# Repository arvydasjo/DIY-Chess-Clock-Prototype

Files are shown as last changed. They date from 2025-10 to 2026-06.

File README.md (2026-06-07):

A personal project for a DIY chess clock. This project includes PCB designs, 3D-printable case files, and firmware for a functional chess clock.

<a href="https://example.com">
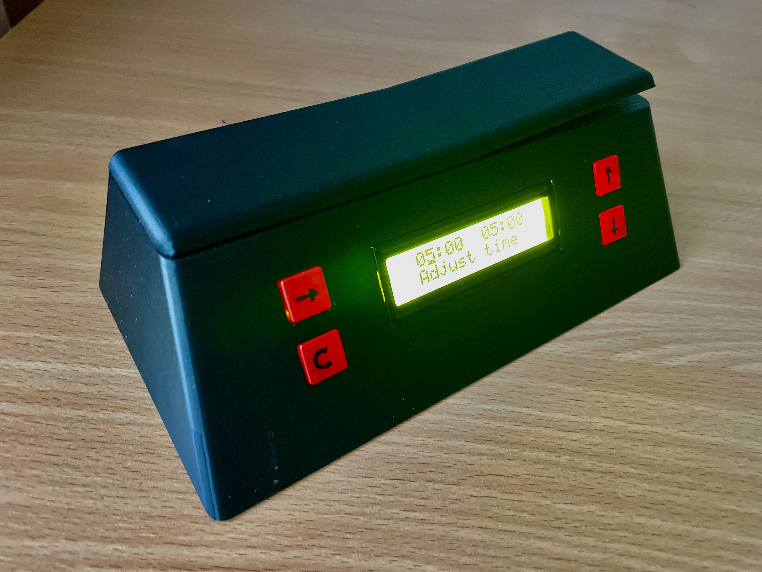
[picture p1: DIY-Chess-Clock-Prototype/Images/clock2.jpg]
  
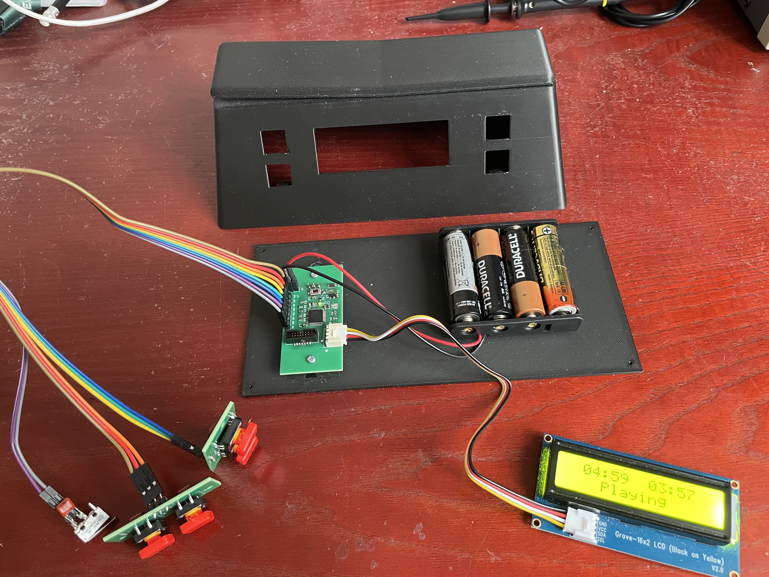
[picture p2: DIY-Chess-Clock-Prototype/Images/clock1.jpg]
  
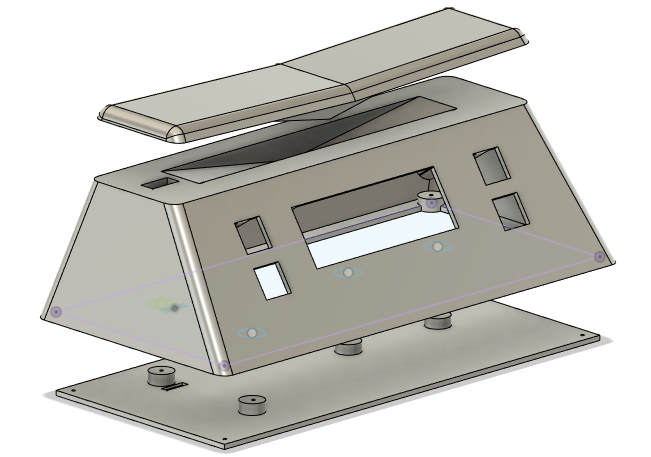
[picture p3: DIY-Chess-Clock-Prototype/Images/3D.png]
  
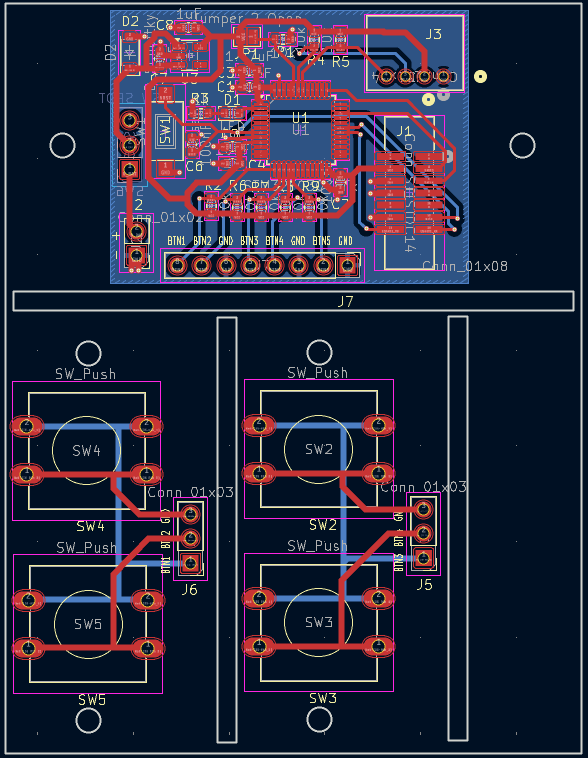
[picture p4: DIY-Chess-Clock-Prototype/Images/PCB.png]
 
</a>

## Features
- Custom PCB with microcontroller STM32F030C8 and screen Grove-LCD 
- 3D-printable case
- small magnets used for the user switch button
- firmware for timing and game management
- Battery-powered

## Files Included
- **PCB/**: Schematic and layout files
- **3D/**: STL files for 3D printing the case
- **Images/**: Prototype pictures
- **Firmware/**: Source code for the microcontroller

## Tools used in the project

- Kicad for PCB design
- STM32CubeIDE + STLINK-V3MINIE for programming, HAL libraries
- Autodesk Fusion for 3D design

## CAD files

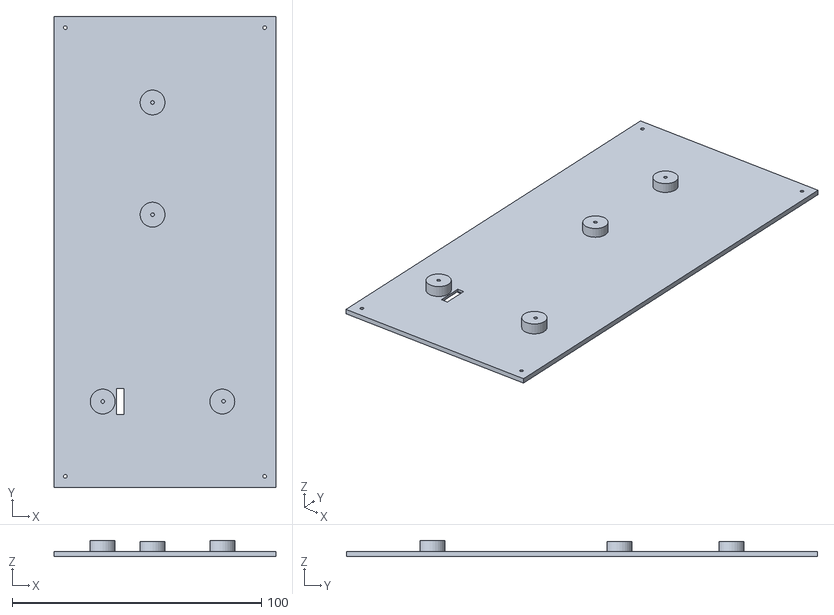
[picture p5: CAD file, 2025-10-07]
DIY-Chess-Clock-Prototype/3D/Box_button.stl
89.0 x 189.0 x 6.50

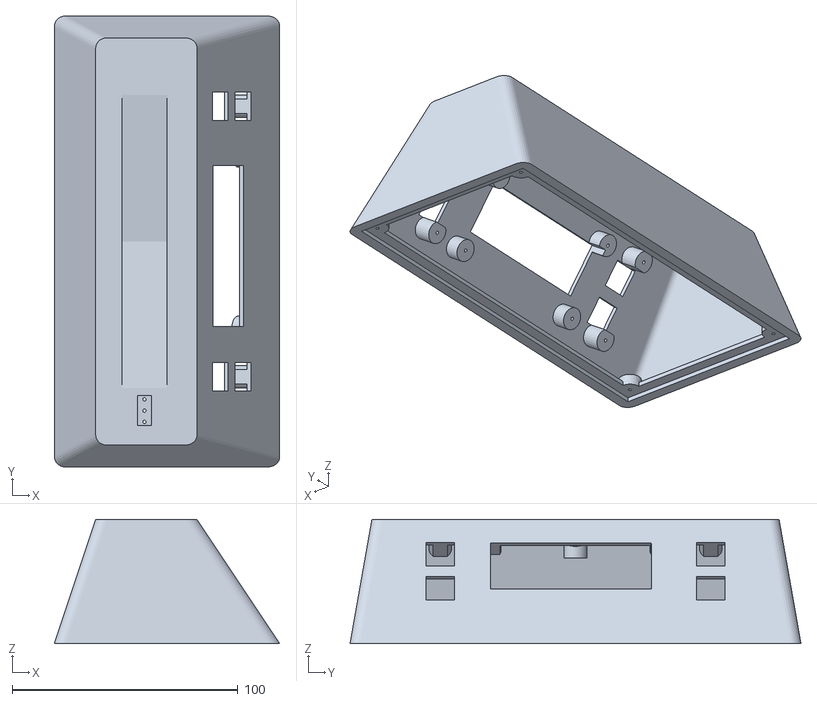
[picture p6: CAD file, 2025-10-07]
DIY-Chess-Clock-Prototype/3D/Box_mid.stl
100.0 x 200.0 x 55.0

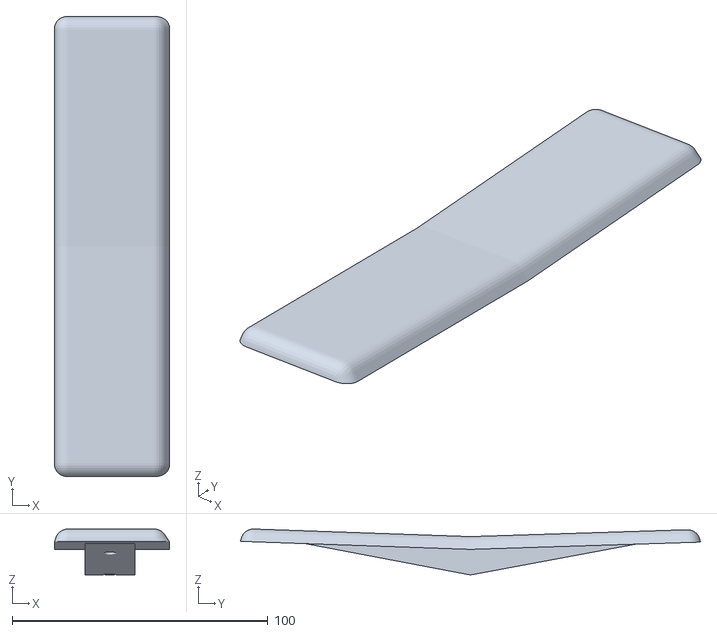
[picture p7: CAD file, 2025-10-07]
DIY-Chess-Clock-Prototype/3D/Box_top.stl
45.0 x 179.8 x 18.0

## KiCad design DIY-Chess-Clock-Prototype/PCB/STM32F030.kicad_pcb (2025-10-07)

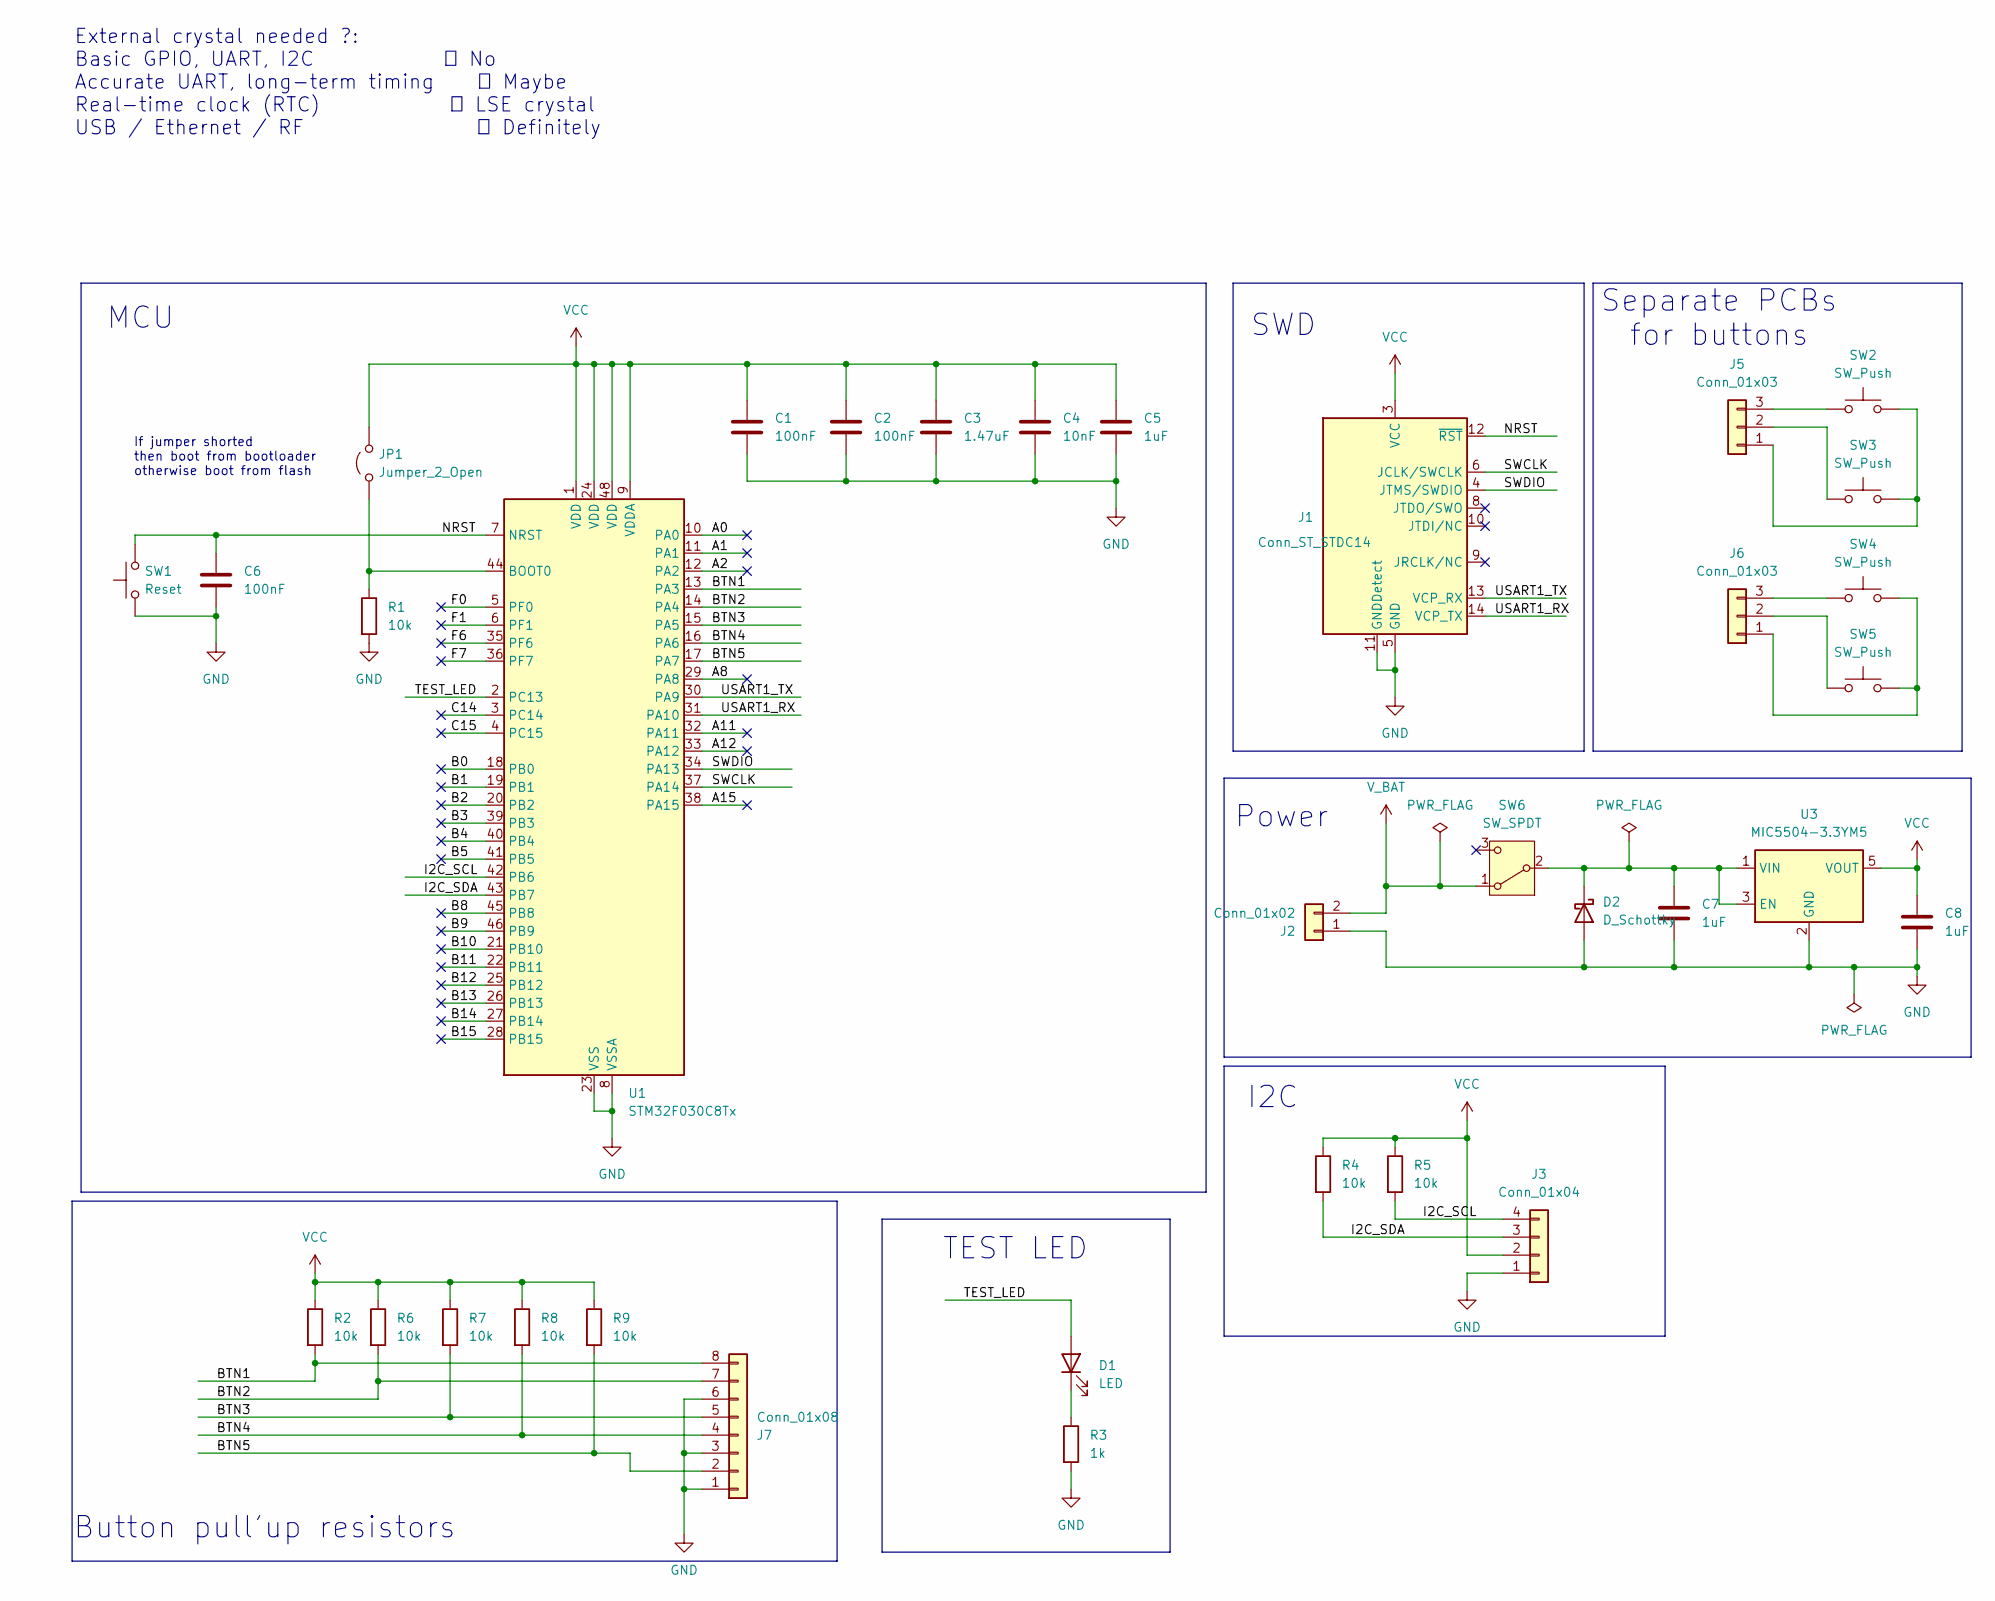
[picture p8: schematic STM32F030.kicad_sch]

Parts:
C1, C2, C6: 100nF; C_0603_1608Metric
C3: 1.47uF; C_0603_1608Metric
C4: 10nF; C_0603_1608Metric
C5, C7, C8: 1uF; C_0603_1608Metric
D1: LED; LED_0603_1608Metric
D2: D_Schottky; D_SOD-123
J1: Conn_ST_STDC14; CONN14_3221-14-0300-00-TR_CNC
J2: Conn_01x02; PinHeader_1x02_P2.54mm_Vertical
J3: Conn_01x04; CONN_S4B-PH-K-S_JST
J5, J6: Conn_01x03; PinHeader_1x03_P2.54mm_Vertical
J7: Conn_01x08; PinHeader_1x08_P2.54mm_Vertical
JP1: Jumper_2_Open; SolderJumper-2_P1.3mm_Open_Pad1.0x1.5mm
R1, R2, R4, R5, R6, R7, R8, R9: 10k; R_0603_1608Metric
R3: 1k; R_0603_1608Metric
SW1: Reset; SW_SPST_CK_RS282G05A3
SW2, SW3, SW4, SW5: SW_Push; SW_PUSH-12mm
SW6: SW_SPDT; PinHeader_1x03_P2.54mm_Vertical
U1: STM32F030C8Tx; LQFP-48_7x7mm_P0.5mm
U3: MIC5504-3.3YM5; SOT-23-5

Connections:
/A0: U1.10 (PA0)
/A1: U1.11 (PA1)
/A2: U1.12 (PA2)
/A8: U1.29 (PA8)
/A11: U1.32 (PA11)
/A12: U1.33 (PA12)
/A15: U1.38 (PA15)
/B0: U1.18 (PB0)
/B1: U1.19 (PB1)
/B2: U1.20 (PB2)
/B3: U1.39 (PB3)
/B4: U1.40 (PB4)
/B5: U1.41 (PB5)
/B8: U1.45 (PB8)
/B9: U1.46 (PB9)
/B10: U1.21 (PB10)
/B11: U1.22 (PB11)
/B12: U1.25 (PB12)
/B13: U1.26 (PB13)
/B14: U1.27 (PB14)
/B15: U1.28 (PB15)
/BTN1: J7.8, R2.2, U1.13 (PA3)
/BTN2: J7.7, R6.2, U1.14 (PA4)
/BTN3: J7.5, R7.2, U1.15 (PA5)
/BTN4: J7.4, R8.2, U1.16 (PA6)
/BTN5: J7.2, R9.2, U1.17 (PA7)
/C14: U1.3 (PC14)
/C15: U1.4 (PC15)
/F0: U1.5 (PF0)
/F1: U1.6 (PF1)
/F6: U1.35 (PF6)
/F7: U1.36 (PF7)
/I2C_SCL: J3.4, R5.2, U1.42 (PB6)
/I2C_SDA: J3.3, R4.2, U1.43 (PB7)
/NRST: C6.1, J1.12 (~RST), SW1.2, U1.7 (NRST)
/SWCLK: J1.6 (JCLK/SWCLK), U1.37 (PA14)
/SWDIO: J1.4 (JTMS/SWDIO), U1.34 (PA13)
/TEST_LED: D1.2 (A), U1.2 (PC13)
/USART1_RX: J1.14 (VCP_TX), U1.31 (PA10)
/USART1_TX: J1.13 (VCP_RX), U1.30 (PA9)
GND: C1.2, C2.2, C3.2, C4.2, C5.2, C6.2, C7.2, C8.2, D2.2 (A), J1.5 (GND), J1.7 (GND), J1.11 (GNDDetect), J2.1, J3.1, J7.1, J7.3, J7.6, R1.2, R3.2, SW1.1, U1.8 (VSSA), U1.23 (VSS), U1.47 (VSS), U3.2 (GND)
unnamed: D1.1 (K), R3.1
unnamed: C7.1, D2.1 (K), SW6.2 (B), U3.1 (VIN), U3.3 (EN)
unnamed: J5.1, SW2.2, SW3.2
unnamed: J5.2, SW3.1
unnamed: J5.3, SW2.1
unnamed: J6.1, SW4.2, SW5.2
unnamed: J6.2, SW5.1
unnamed: J6.3, SW4.1
unnamed: JP1.1 (A), R1.1, U1.44 (BOOT0)
VCC: C1.1, C2.1, C3.1, C4.1, C5.1, C8.1, J1.3 (VCC), J3.2, JP1.2 (B), R2.1, R4.1, R5.1, R6.1, R7.1, R8.1, R9.1, U1.1 (VDD), U1.9 (VDDA), U1.24 (VDD), U1.48 (VDD), U3.5 (VOUT)
V_BAT: J2.2, SW6.1 (A)

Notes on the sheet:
MCU
Button pull'up resistors
Power
If jumper shorted then boot from bootloader otherwise boot from flash
External crystal needed ?: Basic GPIO, UART, I2C ❌ No Accurate UART, long-term timing ✅ Maybe Real-time clock (RTC) ✅ LSE crystal USB / Ethernet / RF ✅ Definitely
SWD
TEST LED
I2C
Separate PCBs for buttons

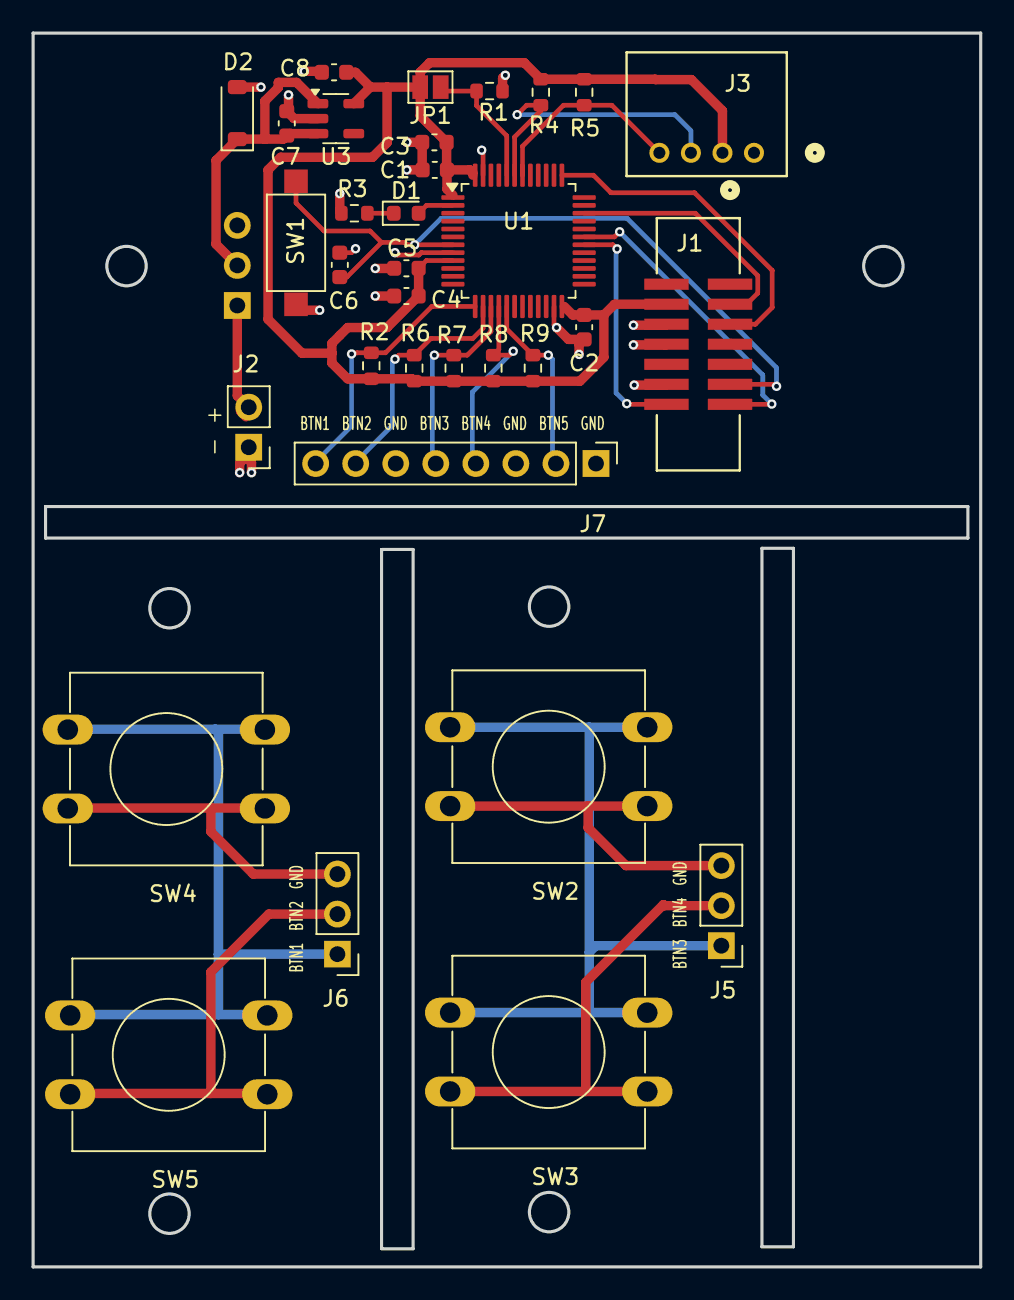
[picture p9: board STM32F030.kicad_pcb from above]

Board: 2 copper layers, 60.1 x 78.2 mm, 34 parts (1 on the bottom side), 25 nets.

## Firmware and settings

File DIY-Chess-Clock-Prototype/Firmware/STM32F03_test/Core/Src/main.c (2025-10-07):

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
/* Includes ------------------------------------------------------------------*/
#include "main.h"

/* USER CODE BEGIN PTD */
typedef enum {CONFIG, READYTOPLAY, PLAY, FINISH} gameStatus_TypeDef;
typedef enum {LEFT, RIGHT} gamePlayer_TypeDef;
typedef enum {ColLeftMin = 3, ColLeftSec = 6, ColRightMin = 10, ColRightSec = 13} CursorCol_TypeDef;


/* USER CODE END PTD */

/* USER CODE BEGIN PD */
#define DEBOUNCE_MS 10 // ms

/* USER CODE END PD */

I2C_HandleTypeDef hi2c1;

TIM_HandleTypeDef htim6;

/* USER CODE BEGIN PV */
static uint8_t LCD_ADR = 0x3E << 1;

gameStatus_TypeDef gameStatus = CONFIG;
gamePlayer_TypeDef gamePlayer = LEFT;
CursorCol_TypeDef cursorCol = ColLeftMin;

 int minLeft = 5;
 int secLeft = 0;

 int minRight = 5;
 int secRight = 0;

 int timeLeft;
 int timeRight;

 uint8_t textLCD[] =            "  00:00  00:00  ";
 uint8_t textLCDConfig[] = 		"  Adjust time   ";
 uint8_t textLCDReadytoPlay[] = " Ready to play  ";
 uint8_t textLCDPlaying[] = 	"    Playing     ";

 uint8_t textLCDWinL[] =        "  Won    Lost   ";
 uint8_t textLCDWinR[] =        "  Lost   Won    ";

char temp[5];

/* USER CODE END PV */

void SystemClock_Config(void);
static void MX_GPIO_Init(void);
static void MX_I2C1_Init(void);
static void MX_TIM6_Init(void);
/* USER CODE BEGIN PFP */
void LCDInit(void);
void LCDInitConfig(void);

void LCDClear(void);
void LCDSetCursor(uint8_t col, uint8_t row);
void LCDPrintStr(uint8_t *str, uint8_t len);
void LCDBlinkOn(void);
void LCDBlinkOff(void);

/* USER CODE END PFP */

/**
  * @brief  The application entry point.
  * @retval int
  */
int main(void)
{

  /* MCU Configuration--------------------------------------------------------*/

  /* Reset of all peripherals, Initializes the Flash interface and the Systick. */
  HAL_Init();

  /* Configure the system clock */
  SystemClock_Config();

  /* Initialize all configured peripherals */
  MX_GPIO_Init();
  MX_I2C1_Init();
  MX_TIM6_Init();
  /* Infinite loop */
  /* USER CODE BEGIN WHILE */

  timeLeft = minLeft*60 + secLeft;
  timeRight = minRight*60 + secRight;


  HAL_TIM_Base_Start_IT(&htim6);

  LCDInit();
  LCDSetCursor(cursorCol, 0);

  while (1)
  {
	//HAL_GPIO_TogglePin(GPIOC, GPIO_PIN_13);
	//HAL_Delay(1000);

	if(gameStatus == CONFIG){
		timeLeft = minLeft*60 + secLeft;
		timeRight = minRight*60 + secRight;
	}

	sprintf(textLCD, "  %02d:%02d  %02d:%02d  ", timeLeft / 60, timeLeft % 60, timeRight / 60, timeRight % 60);
	//memcpy(&textLCD[2], temp, 5);

	//sprintf(temp, "%02d:%02d", timeRight / 60, timeRight % 60);
	//memcpy(&textLCD[9], temp, 5);

	  LCDClear();
	  LCDInit();

	  LCDSetCursor(0, 0);
	  LCDPrintStr(textLCD, 16);


	  if(gameStatus == READYTOPLAY){
		  LCDSetCursor(0, 1);
		  LCDPrintStr(textLCDReadytoPlay, 16);
	  }

	  if(gameStatus == FINISH && timeLeft == 0 && timeRight != 0){
		  LCDSetCursor(0, 1);
		  LCDPrintStr(textLCDWinR, 16);
	  }

	  if(gameStatus == FINISH && timeRight == 0 && timeLeft != 0){
		  LCDSetCursor(0, 1);
		  LCDPrintStr(textLCDWinL, 16);
	  }

	  if(gameStatus == CONFIG){
		  LCDSetCursor(0, 1);
		  LCDPrintStr(textLCDConfig, 16);
	  }

	  if(gameStatus == PLAY){
		  LCDSetCursor(0, 1);
		  LCDPrintStr(textLCDPlaying, 16);
	  }

	  if(gameStatus == CONFIG) LCDBlinkOn();
	  	  else LCDBlinkOff();

	  LCDSetCursor(cursorCol, 0);

	  HAL_Delay(500);

    /* USER CODE END WHILE */

    /* USER CODE BEGIN 3 */
  }
  /* USER CODE END 3 */
}

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
/* USER CODE BEGIN 4 */
void LCDInit(){
	uint8_t arr[2];
	arr[0]=0;

	arr[1]=0xC;
	HAL_I2C_Master_Transmit(&hi2c1,LCD_ADR,arr,2,1000); //Sending in Blocking mode

	arr[1]=0x3F;
	HAL_I2C_Master_Transmit(&hi2c1,LCD_ADR,arr,2,1000); //Sending in Blocking mode

}

void LCDInitConfig(){
	uint8_t arr[2];
	arr[0]=0;

	arr[1]=0xF;
	HAL_I2C_Master_Transmit(&hi2c1,LCD_ADR,arr,2,1000); //Sending in Blocking mode

	arr[1]=0x3F;
	HAL_I2C_Master_Transmit(&hi2c1,LCD_ADR,arr,2,1000); //Sending in Blocking mode

}

void LCDBlinkOn(void) {
    uint8_t arr[2];
    arr[0] = 0x00;    // control byte: command
    arr[1] = 0x0E;    // Display ON, Cursor ON, Blink ON
    HAL_I2C_Master_Transmit(&hi2c1, LCD_ADR, arr, 2, 1000);
}

void LCDBlinkOff(void) {
    uint8_t arr[2];
    arr[0] = 0x00;    // command
    arr[1] = 0x0C;    // Display ON, Cursor OFF, Blink OFF
    HAL_I2C_Master_Transmit(&hi2c1, LCD_ADR, arr, 2, 1000);
}

void LCDClear(void){
	  uint8_t arr[2];
		arr[0]=0x0;
		arr[1]=0x1;
		HAL_I2C_Master_Transmit(&hi2c1,LCD_ADR,arr,2,1000); //Sending in Blocking mode


}

void LCDSetCursor(uint8_t col, uint8_t row) {

    uint8_t arr[2];
    col = (row == 0 ? col | 0x80 : col | 0xc0);
		arr[0]=0x80;
		arr[1]=col;
		HAL_I2C_Master_Transmit(&hi2c1,LCD_ADR,arr,2,1000); //Sending in Blocking mode
}


void LCDPrintStr(uint8_t *str, uint8_t len){

	uint8_t arr[2];
	uint8_t i;
	arr[0]=0x40;

	for(i=0;i<len;i++){
		arr[1]=str[i];
		HAL_I2C_Master_Transmit(&hi2c1,LCD_ADR,arr,2,1000); //Sending in Blocking mode
	}
}


void HAL_TIM_PeriodElapsedCallback(TIM_HandleTypeDef *htim)
{

	if(htim->Instance == TIM6){


		uint16_t suma = 0;

		for(uint16_t i = 0;i < 1000;i++)
		{
			suma+=(HAL_GPIO_ReadPin(GPIOA, GPIO_PIN_7)==GPIO_PIN_SET) ? 0 : 1;
		}

		if(suma > 900)
			gamePlayer = RIGHT;
		else
			gamePlayer = LEFT;


		if(gameStatus == PLAY){
			if(gamePlayer == LEFT)timeLeft --;
				else(timeRight --);

			if(timeLeft == 0 || timeRight == 0) gameStatus = FINISH;

		}


	}
}

void HAL_GPIO_EXTI_Callback(uint16_t GPIO_Pin) {

	static uint32_t last_tick7 = 0;
	static uint32_t last_tick6 = 0;
	static uint32_t last_tick5 = 0;
	static uint32_t last_tick4 = 0;
	static uint32_t last_tick3 = 0;


    if (GPIO_Pin == GPIO_PIN_6 && gameStatus == CONFIG) {
    	if (HAL_GetTick() - last_tick6 > DEBOUNCE_MS) {

    		last_tick6 = HAL_GetTick();

    		if(cursorCol == ColLeftMin) minLeft++;
    		if (minLeft == 61) minLeft = 0;

    		if(cursorCol == ColLeftSec) secLeft++;
    		if(secLeft == 60) secLeft = 0;

    		if(cursorCol == ColRightMin) minRight++;
    		if(minRight == 61) minRight = 0;

    		if(cursorCol == ColRightSec) secRight++;
    		if(secRight == 60) secRight = 0;

    		/*HAL_GPIO_TogglePin(GPIOC, GPIO_PIN_13);*/

    	 }

       }

    if (GPIO_Pin == GPIO_PIN_5 && gameStatus == CONFIG) {
       	if (HAL_GetTick() - last_tick5 > DEBOUNCE_MS) {

       		last_tick5 = HAL_GetTick();

       		if(cursorCol == ColLeftMin) minLeft--;
       		if (minLeft == -1) minLeft = 60;

       		if(cursorCol == ColLeftSec) secLeft--;
       		if(secLeft == -1) secLeft = 59;

       		if(cursorCol == ColRightMin) minRight--;
       		if(minRight == -1) minRight = 60;

       		if(cursorCol == ColRightSec) secRight--;
       		if(secRight == -1) secRight = 59;

       	 }

      }

    if (GPIO_Pin == GPIO_PIN_4 && gameStatus == CONFIG) {
       	if (HAL_GetTick() - last_tick4 > DEBOUNCE_MS) {

       		last_tick4 = HAL_GetTick();

       		int c = cursorCol;

       		switch(c) {
       		    case ColLeftMin:  cursorCol = ColLeftSec;   break;
       		    case ColLeftSec:  cursorCol = ColRightMin;  break;
       		    case ColRightMin: cursorCol = ColRightSec;  break;
       		    case ColRightSec: cursorCol = ColLeftMin;
       		}

       	}
    }

    if (GPIO_Pin == GPIO_PIN_3) {
       	if (HAL_GetTick() - last_tick3 > DEBOUNCE_MS) {

       		last_tick3 = HAL_GetTick();

       		//HAL_GPIO_TogglePin(GPIOC, GPIO_PIN_13);

       		if(HAL_GPIO_ReadPin(GPIOA, GPIO_PIN_3) == GPIO_PIN_RESET)
       		{
       			if(gameStatus == CONFIG) gameStatus = READYTOPLAY;
       			if(gameStatus == PLAY || gameStatus == FINISH) gameStatus = CONFIG;
       		}
       	}
    }




    if (GPIO_Pin == GPIO_PIN_7) {
       	if (HAL_GetTick() - last_tick7 > DEBOUNCE_MS) {

       		last_tick7 = HAL_GetTick();

       		if(gameStatus == READYTOPLAY) gameStatus = PLAY;




       	}

    }

}
/* USER CODE END 4 */
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


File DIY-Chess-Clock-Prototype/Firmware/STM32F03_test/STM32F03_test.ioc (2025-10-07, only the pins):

Mcu.UserName=STM32F030C8Tx
PA13.Signal=SYS_SWDIO
PA14.Signal=SYS_SWCLK
PA3.Signal=GPXTI3
PA4.Signal=GPXTI4
PA5.Signal=GPXTI5
PA6.Signal=GPXTI6
PA7.Signal=GPXTI7
PB6.Signal=I2C1_SCL
PB7.Signal=I2C1_SDA
PC13.Signal=GPIO_Output

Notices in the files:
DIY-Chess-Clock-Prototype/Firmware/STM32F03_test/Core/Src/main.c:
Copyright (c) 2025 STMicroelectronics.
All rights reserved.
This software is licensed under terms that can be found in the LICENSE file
